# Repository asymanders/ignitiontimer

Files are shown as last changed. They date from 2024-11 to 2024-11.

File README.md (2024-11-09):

# Ignition timer

A digital ignition timer for the Matra Murena 2.2 and possibly other cars.

# Background

I started this project for my matra Murena 2.2 because I wanted to be able to time the ignition precisely. The Murena 2.2 was delivered from factory with a diagnostic connector fitted on the engine which had connections to a crank sensor device. The diagnostic connector also had other connections, e.g. to the alternator and sensors on the engine, and the ignition coil circuit from the ignition module. By measuring the time between the crank sensor signal and the ignition coil signal adjusting for the RPM, it would be possible to measure the advance precisely. 

A device that does this is briefly described in one of the original workshop manuals for the engine, however, nobody I've talked to have ever seen such a device, and I've started to doubt whether it existed at all. Also, documentation of the sensor is not available anywhere, so both the device and the sensor remained a mystery.

The sensor fitted looks like a normal, modern sensor, but turned out to be a little odd. Crank sensors are usually either of the Hall-type or pre-magnetized with a permanent magnet. This sensor is more like an inductive proximity sensor with no permanent magnet, but just a coil on what appears to be a ferrite core. It has a rather low DC resistance of about 50 Ohm. The sensor is fitted close to the flywheel which contains two indents, one at TDC and one at TDC + 180 degrees.

# Scope

This project describes the hardware and software of an analogue detector and Microprocessor based device which connects via the Murena diagnostic connector to the sensor and the ignition coil wires,  measures the signals, calculates the RPM and ignition advance, and displays the values in two rows of 7 segment displays. It also has provision for a serial port so that the values can be downloaded to a PC while the engine is running, and subsequently analyzed.

I've designed the device with a classic touch using my favorite MCU, the 8052. It's old and simple, but I wanted to justify that the device could have been made in the 1980's when the car was new. The circuit and PCB is designed in KiCad. The code consists of a single source file written in C for the SDCC compiller. The code is making well use of the three timers to run all the functions of the board, but the code is small and the 8K flahs ROM is far from used. Many of the 256 bytes of RAM are also in surplus.

The analogue section of the board is built around a differential amplifier and acomparator. I've DC-biased the sensor to create a permanent magnetic field which is then disturbed by the flywheel indent. Another comparator (actually the other half of the same IC) is used to detect ignition signals.

# Project history

I started the project in 2023, prototyping ways of making the analogue section. By the end of 2024, I have it working on the engine. The current PCB has several layout issues and I will make an updated version. It's also made for a specific TEKO box which I'm not sure is available from TEKO any more (it is still in stock from my preferred parts dealer).

The is thus still work-in-progress. 

The design is open source. 

# License

Copyright (c) 2024 Anders Dinsen anders@dinsen.net - All rights reserved.

Permission to use, copy, modify, and/or distribute this software for any purpose with or without fee is hereby granted.

THE SOFTWARE IS PROVIDED "AS IS" AND THE AUTHOR DISCLAIMS ALL WARRANTIES WITH REGARD TO THIS SOFTWARE INCLUDING ALL IMPLIED WARRANTIES OF MERCHANTABILITY AND FITNESS. IN NO EVENT SHALL THE AUTHOR BE LIABLE FOR ANY SPECIAL, DIRECT, INDIRECT, OR CONSEQUENTIAL DAMAGES OR ANY DAMAGES WHATSOEVER RESULTING FROM LOSS OF USE, DATA OR PROFITS, WHETHER IN AN ACTION OF CONTRACT, NEGLIGENCE OR OTHER TORTIOUS ACTION, ARISING OUT OF OR IN CONNECTION WITH THE USE OR PERFORMANCE OF THIS SOFTWARE.

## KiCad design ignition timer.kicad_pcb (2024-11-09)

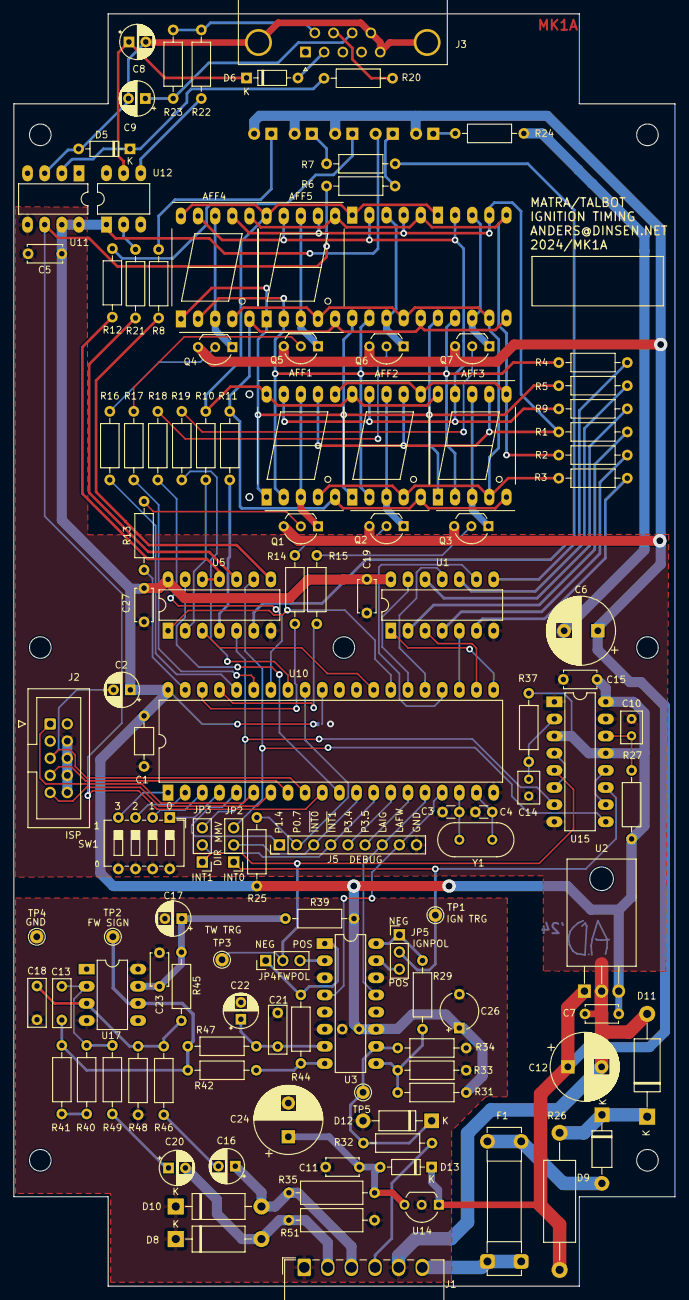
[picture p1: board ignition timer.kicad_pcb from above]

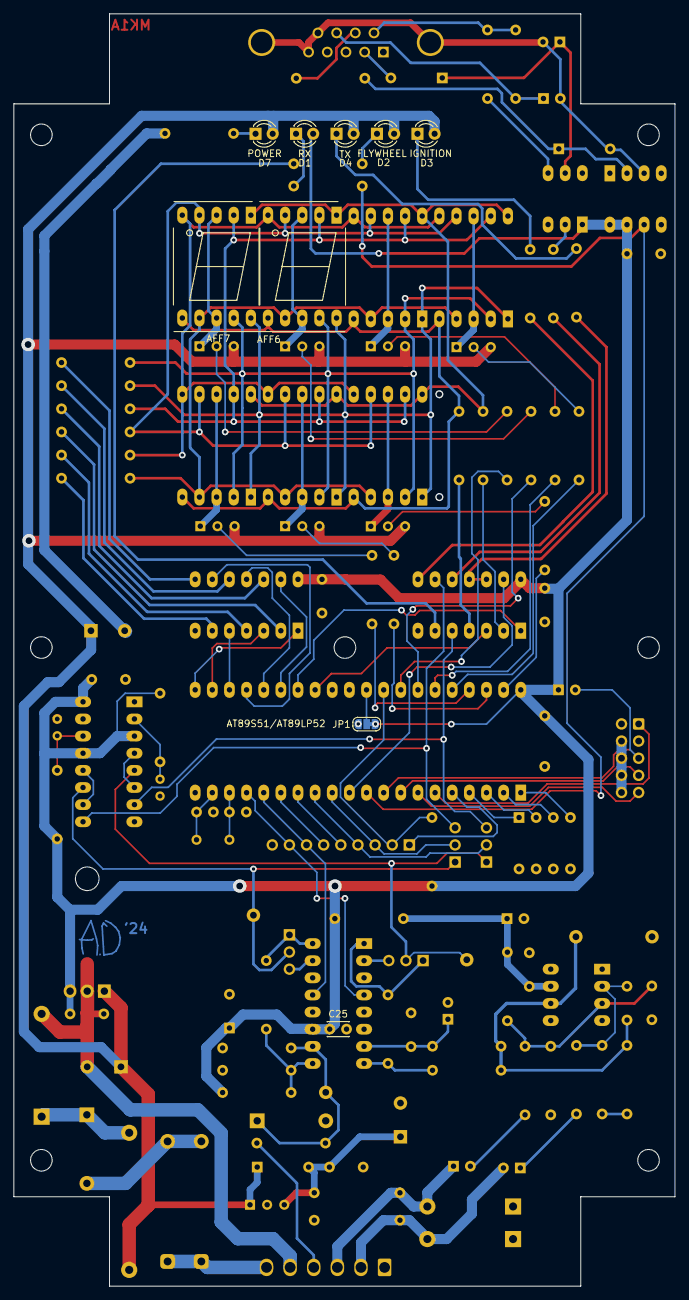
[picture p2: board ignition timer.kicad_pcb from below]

Board: 2 copper layers, 98.0 x 188.6 mm, 126 parts (9 on the bottom side), 116 nets.

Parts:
AFF1, AFF2, AFF3, AFF4, AFF5, AFF6, AFF7: LTS-6960HR; 7SegmentLED_LTS6760_LTS6780
C1: 100N; C_Axial_L3.8mm_D2.6mm_P7.50mm_Horizontal
C2: 1U/63V; CP_Radial_D5.0mm_P2.50mm
C3, C4: 33P; C_Disc_D3.0mm_W1.6mm_P2.50mm
C5: 100N; C_Disc_D5.0mm_W2.5mm_P5.00mm
C6, C12, C24: 470U/25V; CP_Radial_D10.0mm_P5.00mm
C7, C11, C15, C19, C23, C27: 100N; C_Disc_D4.7mm_W2.5mm_P5.00mm
C8, C9: 4U7/63V; CP_Radial_D5.0mm_P2.50mm
C10, C14: 10N; C_Rect_L4.6mm_W3.0mm_P2.50mm_MKS02_FKP02
C13, C18: 10N MKT; C_Rect_L7.0mm_W2.5mm_P5.00mm
C16, C20: 22U/25V; CP_Radial_D5.0mm_P2.50mm
C17: 33U; CP_Radial_D5.0mm_P2.50mm
C21: 10N POLY; C_Rect_L7.0mm_W2.5mm_P5.00mm
C22: 47U/25V; CP_Radial_D5.0mm_P2.50mm
C25: 100N; C_Disc_D3.0mm_W2.0mm_P2.50mm
C26: 10uF/16V TANTAL; CP_Radial_Tantal_D5.5mm_P5.00mm
D1: RX; LED_D3.0mm
D2: FLYWHEEL; LED_D3.0mm
D3: IGNITION; LED_D3.0mm
D4: TX; LED_D3.0mm
D5, D6, D13: 1N4148; D_DO-35_SOD27_P7.62mm_Horizontal
D7: POWER; LED_D3.0mm
D8, D10: TRANSIENTDIODE 13V; D_DO-15_P12.70mm_Horizontal
D9: 1N4007; D_DO-41_SOD81_P10.16mm_Horizontal
D11: TRANSIENTDIODE 15V/600W; D_DO-15_P15.24mm_Horizontal
D12: 4V7/1.3W; D_DO-41_SOD81_P10.16mm_Horizontal
F1: Fuse; Fuseholder_Clip-5x20mm_Bel_FC-203-22_Lateral_P17.80x5.00mm_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
J1: Conn_01x06; Wago_734-166_1x06_P3.50mm_Horizontal
J2: ISP; IDC-Header_2x05_P2.54mm_Vertical
J3: DB9_Female_MountingHoles; DSUB-9_Female_Horizontal_P2.77x2.84mm_EdgePinOffset7.70mm_H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
J5: DEBUG; PinHeader_1x09_P2.54mm_Vertical
JP1: AT89S51/AT89LP52; SolderJumper-3_P1.3mm_Bridged12_RoundedPad1.0x1.5mm_NumberL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
JP2: INT0; PinHeader_1x03_P2.54mm_Vertical
JP3: INT1; PinHeader_1x03_P2.54mm_Vertical
JP4: FWPOL; PinHeader_1x03_P2.54mm_Vertical
JP5: IGNPOL; PinHeader_1x03_P2.54mm_Vertical
Q1, Q2, Q3, Q4, Q5, Q6, Q7: BC557; TO-92_Inline_Wide
R1, R2, R3, R4, R5, R7, R8, R9, R10, R11, R12, R24: 470; R_Axial_DIN0207_L6.3mm_D2.5mm_P10.16mm_Horizontal
R6, R21: 270; R_Axial_DIN0207_L6.3mm_D2.5mm_P10.16mm_Horizontal
R13, R14, R15, R16, R17, R18, R19, R29, R46, R49: 10K; R_Axial_DIN0207_L6.3mm_D2.5mm_P10.16mm_Horizontal
R20, R31, R32, R33: 1K; R_Axial_DIN0207_L6.3mm_D2.5mm_P10.16mm_Horizontal
R22, R42: 100; R_Axial_DIN0207_L6.3mm_D2.5mm_P10.16mm_Horizontal
R23, R34: 1K5; R_Axial_DIN0207_L6.3mm_D2.5mm_P10.16mm_Horizontal
R25: 100K; R_Axial_DIN0207_L6.3mm_D2.5mm_P10.16mm_Horizontal
R26: 1R 1W; R_Axial_DIN0414_L11.9mm_D4.5mm_P20.32mm_Horizontal
R27, R37: 220K; R_Axial_DIN0207_L6.3mm_D2.5mm_P10.16mm_Horizontal
R35, R51: 100/1W; R_Axial_DIN0309_L9.0mm_D3.2mm_P12.70mm_Horizontal
R39: 33; R_Axial_DIN0207_L6.3mm_D2.5mm_P10.16mm_Horizontal
R40: 430; R_Axial_DIN0207_L6.3mm_D2.5mm_P10.16mm_Horizontal
R41: 24K; R_Axial_DIN0207_L6.3mm_D2.5mm_P10.16mm_Horizontal
R44: 33K; R_Axial_DIN0207_L6.3mm_D2.5mm_P10.16mm_Horizontal
R45: 51K; R_Axial_DIN0207_L6.3mm_D2.5mm_P10.16mm_Horizontal
R47: 680; R_Axial_DIN0207_L6.3mm_D2.5mm_P10.16mm_Horizontal
R48: 47K; R_Axial_DIN0207_L6.3mm_D2.5mm_P10.16mm_Horizontal
SW1: SW_DIP_x04; SW_DIP_SPSTx04_Slide_6.7x11.72mm_W7.62mm_P2.54mm_LowProfile
TP1: IGN TRG; Pin_D1.0mm_L10.0mm
TP2: FW SIGN; Pin_D1.0mm_L10.0mm
TP3: TW TRG; Pin_D1.0mm_L10.0mm
TP4: GND; Pin_D1.0mm_L10.0mm
TP5: IGN IN; Pin_D1.0mm_L10.0mm
U1, U5: 7416; DIP-14_W7.62mm_LongPads
U2: LM7805_TO220; TO-220-3_Horizontal_TabDown
U3: MAX912CPE; DIP-16_W7.62mm_LongPads
U10: AT89S51-24PI; DIP-40_W15.24mm_LongPads
U11: 6N137; DIP-8_W7.62mm_LongPads
U12: 4N37; DIP-6_W7.62mm_LongPads
U14: LM78L09; TO-92_Inline_Wide
U15: 74HCT4538; DIP-16_W7.62mm_LongPads
U17: TLC271; DIP-8_W7.62mm_LongPads
Y1: 11.059200 MHz; Crystal_HC49-U_Vertical

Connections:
+9V: C11.2, C24.1, D13.2 (A), R35.1, U14.3 (VO)
+12V: C6.1, C12.1, D2.2 (A), D3.2 (A), D4.2 (A), D7.2 (A), D13.1 (K), Q1.3 (E), Q2.3 (E), Q3.3 (E), Q4.3 (E), Q5.3 (E), Q6.3 (E), Q7.3 (E), R26.1, U2.1 (VI), U14.1 (VI)
/A: AFF1.7 (a), AFF2.7 (a), AFF3.7 (a), AFF4.7 (a), AFF5.7 (a), AFF6.7 (a), AFF7.7 (a), R1.2
/B: AFF1.6 (b), AFF2.6 (b), AFF3.6 (b), AFF4.6 (b), AFF5.6 (b), AFF6.6 (b), AFF7.6 (b), R2.1
/C: AFF1.4 (c), AFF2.4 (c), AFF3.4 (c), AFF4.4 (c), AFF5.4 (c), AFF6.4 (c), AFF7.4 (c), R3.1
/CIRCUIT 10 (IGNITION): J1.4, R32.2
/D: AFF1.2 (d), AFF2.2 (d), AFF3.2 (d), AFF4.2 (d), AFF5.2 (d), AFF6.2 (d), AFF7.2 (d), R4.1
/DP: AFF1.5 (DP), AFF2.5 (DP), AFF3.5 (DP), AFF4.5 (DP), AFF5.5 (DP), AFF6.5 (DP), AFF7.5 (DP), R11.1
/E: AFF1.1 (e), AFF2.1 (e), AFF3.1 (e), AFF4.1 (e), AFF5.1 (e), AFF6.1 (e), AFF7.1 (e), R5.1
/F: AFF1.9 (f), AFF2.9 (f), AFF3.9 (f), AFF4.9 (f), AFF5.9 (f), AFF6.9 (f), AFF7.9 (f), R9.1
/G: AFF1.10 (g), AFF2.10 (g), AFF3.10 (g), AFF4.10 (g), AFF5.10 (g), AFF6.10 (g), AFF7.10 (g), R10.1
/LATCH FW: J5.8, U3.4 (LATCH), U10.17 (P3.7/~RD)
/LATCH IGN: J5.7, U3.13 (LATCH), U10.16 (P3.6/~WR)
/MISO: J2.9, U10.7 (P1.6/MISO)
/MOSI: J2.1, U10.6 (P1.5/MOSI)
/RST: C2.2, J2.5, U10.9 (RST)
/SCK: J2.7, U10.8 (P1.7/SCK)
/SENSOR+: C16.1, D10.2 (A2), J1.3, R35.2
/SENSOR-: C20.2, D8.2 (A2), J1.2, R51.1
/~CA0: R13.1, U10.39 (P0.0/AD0)
/~CA1: R14.1, U10.38 (P0.1/AD1)
/~CA2: R15.1, U10.37 (P0.2/AD2)
/~CA3: R16.1, U10.36 (P0.3/AD3)
/~CA4: R17.2, U10.35 (P0.4/AD4)
/~CA5: R18.2, U10.34 (P0.5/AD5)
/~CA6: R19.1, U10.33 (P0.6/AD6)
/~EA/VPP: JP1.2 (C), U10.31 (~EA/VPP)
/~FWTRG: JP3.1 (A), JP4.2 (C), TP3.1, U15.5 (Clk-)
/~IGNTRG: JP2.1 (A), JP5.2 (C), TP1.1, U15.11 (Clk-)
/~INT0: J5.3, JP2.2 (C), U10.12 (P3.2/~INT0)
/~INT1: J5.4, JP3.2 (C), U10.13 (P3.3/~INT1)
GND: C1.2, C3.1, C4.1, C5.2, C6.2, C7.2, C10.2, C11.1, C12.2, C14.2, C15.2, C17.2, C18.1, C19.2, C21.2, C22.2, C23.2, C24.2, C25.2, C26.2, C27.2, D8.1 (A1), D10.1 (A1), D11.2 (A2), D12.2 (A), J1.1, J1.5, J2.4, J2.6, J2.8, J2.10, J5.9, JP1.3 (B), R24.1, R33.1, R34.2, R48.2, R51.2, SW1.5, SW1.6, SW1.7, SW1.8, TP4.1, U1.7 (GND), U2.2 (GND), U3.3 (GND), U3.6 (V-), U3.14 (GND), U5.7 (GND), U10.20 (GND), U11.5 (GND), U14.2 (GND), U15.1 (Cx), U15.8 (VSS), U15.15 (Cx), U17.4 (V-), U17.8 (BIAS)
unnamed: C13.2, R41.1, R42.2, R47.2, TP2.1, U17.6
unnamed: C16.2, R46.2
unnamed: C20.1, R49.2
unnamed: D1.1 (K), R6.2
unnamed: D2.1 (K), R7.2
unnamed: D3.1 (K), R8.2
unnamed: D4.1 (K), R12.2
unnamed: C8.2, C9.2, D5.2 (A), J3.0 (PAD), J3.5, J3.9, U11.3 (C)
unnamed: D5.1 (K), R20.1, U11.2 (A)
unnamed: D6.2 (A), J3.2
unnamed: C8.1, D6.1 (K), U12.5
unnamed: D7.1 (K), R24.2
unnamed: D9.2 (A), F1.2
unnamed: D9.1 (K), D11.1 (A1), R26.2
unnamed: D12.1 (K), R32.1, R34.1, TP5.1, U3.10 (-)
unnamed: F1.1, J1.6
unnamed: J3.6, R22.2, R23.2
unnamed: J3.7, R20.2
unnamed: J5.1, U10.5 (P1.4)
unnamed: J5.2, R25.2, U10.32 (P0.7/AD7)
unnamed: J5.5, U10.14 (P3.4/T0)
unnamed: J5.6, U10.15 (P3.5/T1)
unnamed: JP2.3 (B), U5.9, U15.9 (~Q)
unnamed: JP3.3 (B), U5.5, U15.7 (~Q)
unnamed: JP4.1 (A), R44.1, U3.1 (Q)
unnamed: JP4.3 (B), U3.2 (~Q)
unnamed: JP5.1 (A), R29.1, U3.16 (Q)
unnamed: JP5.3 (B), U3.15 (~Q)
unnamed: Q1.2 (B), R13.2
unnamed: AFF1.3 (C.A.), AFF1.8 (C.A.), Q1.1 (C)
unnamed: Q2.2 (B), R14.2
unnamed: AFF2.3 (C.A.), AFF2.8 (C.A.), Q2.1 (C)
unnamed: Q3.2 (B), R15.2
unnamed: AFF3.3 (C.A.), AFF3.8 (C.A.), Q3.1 (C)
unnamed: Q4.2 (B), R16.2
unnamed: AFF4.3 (C.A.), AFF4.8 (C.A.), Q4.1 (C)
unnamed: Q5.2 (B), R17.1
unnamed: AFF5.3 (C.A.), AFF5.8 (C.A.), Q5.1 (C)
unnamed: Q6.2 (B), R18.1
unnamed: AFF6.3 (C.A.), AFF6.8 (C.A.), Q6.1 (C)
unnamed: Q7.2 (B), R19.2
unnamed: AFF7.3 (C.A.), AFF7.8 (C.A.), Q7.1 (C)
unnamed: R1.1, U1.2
unnamed: R2.2, U1.4
unnamed: R3.2, U1.6
unnamed: R4.2, U1.8
unnamed: R5.2, U1.10
unnamed: R7.1, U5.6
unnamed: R8.1, U5.8
unnamed: R9.2, U1.12
unnamed: R10.2, U5.2
unnamed: R11.2, U5.4
unnamed: R12.1, U5.11, U5.12
unnamed: R21.1, U5.10
unnamed: R21.2, U12.2
unnamed: R22.1, U12.4
unnamed: R40.1, R41.2
unnamed: R42.1, R44.2, U3.8 (+)
unnamed: C21.1, C22.1, R47.1, U3.7 (-)
unnamed: R29.2, R31.1, R33.2, U3.9 (+)
unnamed: SW1.4, U10.1 (P1.0)
unnamed: SW1.3, U10.2 (P1.1)
unnamed: SW1.2, U10.3 (P1.2)
unnamed: SW1.1, U10.4 (P1.3)
unnamed: U1.1, U10.21 (P2.0/A8)
unnamed: U1.3, U10.22 (P2.1/A9)
unnamed: U1.5, U10.23 (P2.2/A10)
unnamed: U1.9, U10.24 (P2.3/A11)
unnamed: U1.11, U10.25 (P2.4/A12)
unnamed: U1.13, U10.26 (P2.5/A13)
unnamed: U5.1, U10.27 (P2.6/A14)
unnamed: U5.3, U10.28 (P2.7/A15)
unnamed: R6.1, U10.10 (P3.0/RXD), U11.6 (VO)
unnamed: U5.13, U10.11 (P3.1/TXD)
unnamed: C4.2, U10.19 (XTAL1), Y1.1
unnamed: C3.2, U10.18 (XTAL2), Y1.2
unnamed: U15.4 (Clk+), U15.6 (Q)
unnamed: C14.1, R37.1, U15.2 (RxCx)
unnamed: U15.10 (Q), U15.12 (Clk+)
unnamed: C10.1, R27.1, U15.14 (RxCx)
unnamed: C18.2, R45.2, R46.1, R48.1, U17.3 (+)
unnamed: C13.1, R40.2, R49.1, U17.2 (-)
VCC: C1.1, C2.1, C5.1, C7.1, C15.1, C19.1, C25.1, C26.1, C27.1, D1.2 (A), JP1.1 (A), R25.1, R27.2, R31.2, R37.2, R39.1, U1.14 (VCC), U2.3 (VO), U3.11 (V+), U5.14 (VCC), U10.40 (VCC), U11.7 (EN), U11.8 (VCC), U12.1, U15.3 (R), U15.13 (R), U15.16 (VDD)
VSSA: C17.1, C23.1, R39.2, R45.1, U17.7 (V+)

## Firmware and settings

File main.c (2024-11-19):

/* Matra Murena Ignition Timer
 *
 * Copyright (c) 2024 Anders Dinsen anders@dinsen.net - All rights reserved.
 *
 * Permission to use, copy, modify, and/or distribute this software for any
 * purpose with or without fee is hereby granted.
 *
 * THE SOFTWARE IS PROVIDED "AS IS" AND THE AUTHOR DISCLAIMS ALL WARRANTIES
 * WITH REGARD TO THIS SOFTWARE INCLUDING ALL IMPLIED WARRANTIES OF
 * MERCHANTABILITY AND FITNESS. IN NO EVENT SHALL THE AUTHOR BE LIABLE FOR
 * ANY SPECIAL, DIRECT, INDIRECT, OR CONSEQUENTIAL DAMAGES OR ANY DAMAGES
 * WHATSOEVER RESULTING FROM LOSS OF USE, DATA OR PROFITS, WHETHER IN AN
 * ACTION OF CONTRACT, NEGLIGENCE OR OTHER TORTIOUS ACTION, ARISING OUT OF
 * OR IN CONNECTION WITH THE USE OR PERFORMANCE OF THIS SOFTWARE.
 */

/* Target board configuration: */
#undef CRYSTAL22
#define FLIPPEDDISPLAYS

#include <at89x52.h>

/* 89S51 registers not in the at89x51.h */
__sfr __at 0x8E AUXR;
__sfr __at 0xA2 AUXR1;
__sfr __at 0xA6 WDTRST;

#include <stdlib.h>

#ifdef CRYSTAL22
#define MINCOUNT 5532; 
#define	IGNITION_FACTOR 55312384L 
#else
#define MINCOUNT 2766;
#define	IGNITION_FACTOR 27656192L 
#endif

#ifdef FLIPPEDDISPLAYS
static const unsigned char rpm_display[] = {3,4,5,6};
static const unsigned char deg_display[] = {0,1,2};
#else
static const unsigned char rpm_display[] = {6,5,4,3};
static const unsigned char deg_display[] = {2,1,0};
#endif

/* The physical offset of the flywheel notch in degrees from TDC is 28 degrees: */
#define FW_OFFSET 28 

#define LATCH_FW P3_7
#define LATCH_IGN P3_6

/* Global flags */
volatile __bit f_ignition_interrupt;
volatile __bit f_crank_interrupt;

/* Other global variables */

volatile union _byte_addressable_long { 
	unsigned long l;
	struct {
		unsigned int w0;
		unsigned int w1;
	} w;
	struct {
		unsigned char b0;
		unsigned char b1;
		unsigned char b2;
		unsigned char b3;
	} b;
} t_ignition;

volatile union _byte_addressable_long t_crank;

volatile unsigned char timer0_extension;
volatile unsigned char digits[7];
volatile unsigned char display_digit;
volatile unsigned char mask_digit;
volatile int timer_tick;
volatile char user_command;
volatile unsigned char ms_counter;
volatile unsigned char rpm[4];
volatile unsigned char adv[3];

#ifdef FLIPPEDDISPLAYS
/* LED displays are flipped to the rear of the PCB so the bits are permutated:
 * bit 0 => F
 * bit 1 => G
 * bit 2 => D
 * bit 3 => C
 * bit 4 => DP
 * bit 5 => A
 * bit 6 => B
 * bit 7 => E */
static const unsigned char s7[] = {
	0b11101101, /* 0 ABCDEF  */
	0b01001000, /* 1  BC     */
	0b11100110, /* 2 AB DE G */
	0b01101110, /* 3 ABCD  G */
	0b01001011, /* 4  BC  FG */
	0b00101111, /* 5 A CD FG */
	0b10101111, /* 6 A CDEFG */
	0b01101000, /* 7 ABC     */
	0b11101111, /* 8 ABCDEFG */
	0b01101111, /* 9 ABCD FG */ 
	0b11101011, /* A ABC EFG*/ 
	0b10001111, /* b   CDEFG */ 
	0b10000110, /* c    DE G */ 
	0b11001110, /* d  BCDE G */ 
	0b10100111, /* E A  DEFG */ 
	0b10100011  /* F A   EFG */ 
};
#define LED_DASH	(2)
#define LED_DP		(16)
#else
/* LED displays are fitted on the front of the PCB as per the original design:
 * bit 0 => A
 * bit 1 => B
 * bit 2 => C
 * bit 3 => D
 * bit 4 => E
 * bit 5 => F
 * bit 6 => G
 * bit 7 => DP */
static const unsigned char s7[] = {
	0b00111111, /* 0 */
	0b00000110, /* 1 */
	0b01011011, /* 2 */
	0b01001111, /* 3 */
	0b01100110, /* 4 */
	0b01101101, /* 5 */
	0b01111101, /* 6 */
	0b00000111, /* 7 */
	0b01111111, /* 8 */
	0b01101111, /* 9 */ 
	0b01110111, /* A */ 
	0b01111100, /* b */ 
	0b01011000, /* c */ 
	0b01011110, /* d */ 
	0b01111001, /* E */ 
	0b01110001  /* F */ 
};
#define LED_DASH	(64)
#define LED_DP		(128)
#endif

/* Interrupt routines
 * INT0 = Ignition trigger
 * INT1 = Timer 0 (16 bit counting) 
 * INT2 = Flywheel trigger
 * INT3 = Timer 1 (unused)
 * INT4 = UART
 * INT5 = Timer 2 (display)
 */

/* ignition interrupt routine, main job is to save the timer0 for later calculation and then restart from 0 */

void ignition_isr(void) __interrupt (0) {
	t_ignition.b.b0 = TL0;
	t_ignition.b.b1 = TH0;
	t_ignition.b.b2 = timer0_extension;
	TL0 = TH0 = timer0_extension = 0;
	LATCH_FW = 0; /* unlatch flywheel trigger circuit */
	TF0 = 0;
	f_ignition_interrupt = 1;
	P3_5 = 0;
}

/* timer0 overflow interrupt routine extends timer0 to 24 bits */

void timer0_isr(void) __interrupt (1) {
	timer0_extension++;
	P3_5 = 1;
}

/* crank interrupt routine saves the timer0 including 8 bit extension in the crank time variable for later calculations */

void crank_isr(void) __interrupt (2) {
	f_crank_interrupt = 1;
	t_crank.b.b0 = TL0;
	t_crank.b.b1 = TH0;
	t_crank.b.b2 = timer0_extension;
	LATCH_FW = 1; /* latch flywheel trigger circuit to prevent it from picking up noise until next ignition */
}

/* uart interrupt reads watever user command character is received 
 * TODO implement interrupt and buffered output, emit a character from an output buffer */

void uart_isr(void) __interrupt (4) {
	if ( RI ) {
		user_command = SBUF;
		RI = 0;
	}
}

/* timer 2 interrupt runs the refresh of the display and a miliseconds counter for precise main loop timing */

void digits_isr(void) __interrupt (5) {
	P1_4 = 0; /* test output to measure interrupt time */

	EXF2 = 0;
	TF2 = 0;

	/* next display digit, calculate mask */
	if ( display_digit ) {
		display_digit--;
		mask_digit |= 128;
		mask_digit >>= 1;
	}
	else {
		display_digit = 6;
		mask_digit = (unsigned char)0b10111111;
	}

	/* display digit */
	P2 = 0;
	P0 = mask_digit;
	P2 = digits[display_digit];

	ms_counter++;

	P1_4 = 1; /* reset test output */
}

/* this function should be called to set a start point in time from which delay is measured */

void inline delay_start(void) {
	ms_counter = 0;
}

/* this function sleeps until d ms has passed since delay_start() was called */

void inline delay_ms(unsigned char d) {
	while ( ms_counter < d ) {
		WDTRST = 0x1e;
		WDTRST = 0xe1; 
	}
}

/* UART utility routines
 * TODO rewrite to use a small output buffer and output characters by interrupts */

void inline emit_char(char c) {
	SBUF=c;
	while ( !TI ) {
		WDTRST = 0x1e;
		WDTRST = 0xe1;
	}
	TI=0; 
}

void emit_string(__code char *s) {
	while( *s ) 
		emit_char(*s++);
}


/* main loop where all processing occurs and state is maintained. */

void main(void) {
	unsigned char i, j; 
	unsigned char n = 0;
	long l;
	__bit f_ign_overflow;

	/* ports init */
	P0 = 255; /* All displays off */
	P1 = 255; /* P1 are inputs */
	P2 = 0; /* All segments off */
	P3 = 63; /* Latch off detectors, other pins are serial I/O, interrupt inputs and debug outputs */

	/* global variables initialization */
	timer_tick = 0;
	user_command = 0;
	display_digit = 0;
	ms_counter = 0;
	mask_digit = (unsigned char)0b10111111;
	timer0_extension = 0;

	/* Timer and UART init */
	TMOD	= 0x21;	/* Timer 0 in 16 bit (mode 1), Timer 1 in 8 bit autoreload (mode 2) */

	/* PCON 	|= 0x80; Double baud rate */
	TH1	= 0xfa; /* 4800 Baud rate at 11.0592 MHz, 9600 Baud rate at 22.1184 MHz */
	TL1	= 0;
	SCON	= 0x50; /* Asynchronous mode 8-bit data, 1-stop bit */
	TR1	= 1;	/* Start baud rate generator */

	/* Timer 0 is used as a free-running 16 bit counter */
	TL0 = TH0 = 0;
	TF0	= 0;	/* clear timer 0 overflow flag */
	TR0	= 1;	/* Start timer 0 */

	/* Timer 2 is used for the display refresh at 1 kHz */
	T2CON	= 0b00000100; /* automatic relad timer 2, start timer 2 */
	T2MOD	= 0;
	TL2	= 0;
	TH2	= 0;
#ifdef CRYSTAL22
	RCAP2H	= 0xF8;
	RCAP2L	= 0xCD;
#else	
	RCAP2H	= 0xFC;
	RCAP2L	= 0x67;
#endif

	IT1 = IT0 = 1;  /* INT0 and INT1 are both falling edge triggered */

	/* Other inits */
	AUXR = 0b00011000; /* WDIDLE = 1, watch dog timer continues counting
			      in idle mode 
	                      DISRTO = 1, reset pin is input only
			      DISALE = 0, ALE is emitted */

	IE = 0b10110111; /* EA = 1, enable all interrupts
			    Unused bit = 0
			    ET2 = 1, enable timer 2 interrupt
			    ES = 1, enable serial port interrupt
			    ET1 = 0, disable timer 1 interrupt
			    EX1 = 1, enable external interrupt 1
			    ET0 = 1, disable timer 0 interrupt
			    EX0 = 1, enable external interrupt 0 */
	
	IP = 0b00000101; /* the two external interrupts takes interrupt priority over the timers and serial port */

	LATCH_FW = LATCH_IGN = 0;

	l = 0;
	delay_start();
	while (1) {
		WDTRST = 0x1e;
		WDTRST = 0xe1;

		P3_4 = 0; /* debug output to time calculations */

		if ( P1_2 && P1_3 /* dip switches 3 & 4 both off */ ) {
			/* TEST MODE: serial output test */
			emit_string("SERIAL OUTPUT TEST MODE\r\n");
		}
		else if ( P1_2 && !P1_3 /* dip switches 3 off & 4 on */ ) {
			/* Display test mode */
			for (i=6; i != 255; i--) 
				digits[i] = s7[(n & 31) >> 1] | (i==(n&7)? LED_DP : 0);
			n++;
		}
		else if ( f_ignition_interrupt ) {
			if ( P1_1 /* dip switch 2 off */ ) {
				/* TEST MODE: display timer values directly in hex */
				digits[deg_display[0]] = f_crank_interrupt? s7[t_crank.b.b0 & 15] : LED_DASH;
				digits[deg_display[1]] = f_crank_interrupt? s7[t_crank.b.b0 >> 4] : LED_DASH;
				digits[deg_display[2]] = f_crank_interrupt? s7[t_crank.b.b1 & 15] : LED_DASH;

				if ( t_crank.b.b1 & 16 ) 
					digits[deg_display[0]] |= LED_DP;
				if ( t_crank.b.b1 & 32 ) 
					digits[deg_display[1]] |= LED_DP;
				if ( t_crank.b.b1 & 64 ) 
					digits[deg_display[2]] |= LED_DP;

				digits[rpm_display[0]] = s7[t_ignition.b.b0 & 15];
				digits[rpm_display[1]] = s7[t_ignition.b.b0 >> 4];
				digits[rpm_display[2]] = s7[t_ignition.b.b1 & 15];
				digits[rpm_display[3]] = s7[t_ignition.b.b1 >> 4];

				if ( t_ignition.b.b2 & 1 ) 
					digits[rpm_display[0]] |= LED_DP;
				if ( t_ignition.b.b2 & 2 ) 
					digits[rpm_display[1]] |= LED_DP;
				if ( t_ignition.b.b2 & 4 ) 
					digits[rpm_display[2]] |= LED_DP;
				if ( t_ignition.b.b2 & 8 ) 
					digits[rpm_display[3]] |= LED_DP;
				f_crank_interrupt = 0;
			}
			else {
				/* calcuate and display RPM and crank angle */
				f_ign_overflow = t_ignition.l < MINCOUNT; 
				l = IGNITION_FACTOR / t_ignition.l;

				for (i=0, j=3; i<4; i++, j--) {
					if ( f_ign_overflow ) 
						n = 9;
					else
						n = (unsigned char)(l % 10);
					digits[rpm_display[i]] = s7[n];
					rpm[j] = n;
					l /= 10;
				}

				if ( P1_3 /* dip switch 1 off */ ) {
					for (j=0; j<4; j++) emit_char(rpm[j]+'0');
					emit_char(' ');
				}

				if ( f_crank_interrupt ) {
					/* crank signal detected, calculate advance */
					l = ( 180 * t_crank.l ) / t_ignition.l - FW_OFFSET; 
					for (i=0; i<3; i++) {
						n = (unsigned char)(l % 10);
						digits[deg_display[i]] = s7[n];
						adv[i] = n;
						l /= 10;
					}
					if ( P1_3 ) {
						for (j=0; j<3; j++) emit_char(adv[j]+'0');
					}

					f_crank_interrupt = 0;
				}
				else {
					/* no crank signal detected, dash out advance digits */
					for (i=0; i<3; i++) 
						digits[i] = LED_DASH;
				}

				if ( P1_3 ) {
					emit_char('\r');
					emit_char('\n');
				}
			}
		}
		else {
			/* no ignition detected since last round of the main loop, dash out all digits */
			for (i=0; i<7; i++)
				digits[i] = LED_DASH;
			f_crank_interrupt = 0;
		}

		f_ignition_interrupt = 0;

		if ( user_command ) {
			/* for now, just echo whatever is typed on the serial port */
			emit_char(user_command);
			if ( user_command == '\r' )
				emit_char('\n');
			user_command = '\0';
		}

		P3_4 = 1; /* debug for measuring the time it takes to run the main loop */

		delay_ms(250); /* update display four times a second */
		delay_start();
	}; 
}

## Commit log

2024-11-09 Update license and target board configurations
2024-11-19 Fixed messed up flipped displays
    [main.c]
